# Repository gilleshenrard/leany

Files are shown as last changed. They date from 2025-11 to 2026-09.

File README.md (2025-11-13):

<!--
SPDX-FileCopyrightText: 2025 Gilles Henrard <contact@gilleshenrard.com>

SPDX-License-Identifier: MIT
-->

# Leany - An open-Source Inclinometer

Leany is a fully open-source, production-ready inclinometer based on an ARM Cortex-M3 32-bits microcontroller.
It provides high-precision tilt measurements while adhering to strict embedded software and hardware design standards.

## About the Project
An inclinometer is a tool that measures how much something is tilted, specifically in two directions: pitch and roll.

- Pitch measures the tilt forward or backward. Imagine tilting your head down to look at your feet—that’s pitch.
- Roll measures the tilt side to side. It’s like tilting your head left or right to look over your shoulder—that’s roll.

So, if you're using an inclinometer, it can tell you exactly how much something is tilted forward, backward, or side to side. For example, if you're setting up equipment, you can use the inclinometer to make sure it’s positioned correctly, with no unwanted tilt in either direction. It’s useful in many situations, from construction to vehicles, ensuring that everything is set at the right angle for safety and precision.

Leany is designed for engineers, makers, and professionals who need a reliable, open, and customizable inclinometer. It offers precise tilt measurements and multiple operating modes while maintaining a strong focus on code quality, hardware reliability, and ease of integration.

### Key Features

- **Measurements**: Supports pitch and roll rotation axes with a precision of up to **0.1°**.
- **Hold Function**: Freezes screen updates to keep a measurement visible.
- **Slope Mode**: Measures angles relative to gravity (**absolute measurements**).
- **Angle Mode**: Measures angles relative to a user-defined zero position (**relative measurements**).

## Getting Started

Before contributing, please run the following :
```
git config --local include.path ../.gitconfig
```

To learn more about each part of the project, check the respective directories:

- **[Firmware (`firmware/`)](firmware/)** – Contains the firmware source code and instructions on how to build and flash it.
- **[PCB Design (`pcb/`)](pcb/)** – Contains the schematics and board design, along with instructions on generating production files.
- **[Documentation templates (`templates/`)](templates/)** – Contains example files to illustrate the structure documentation files should have.

## Contributions & Community

Leany is managed with the help of a **[Github Project](https://github.com/users/gilleshenrard/projects/3)**

Leany is fully open-source, and contributions are welcome! If you find a bug, have a suggestion, or want to improve the project, feel free to open an issue or submit a pull request.

Discussions are also encouraged—whether it's feature ideas, improvements, or troubleshooting. Join the community and help make Leany even better!

## License

This project is licensed under the **MIT License**, allowing for flexible use and modification.

---

Feel free to suggest any changes or enhancements to this README! 🚀

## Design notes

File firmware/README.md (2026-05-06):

<!--
SPDX-FileCopyrightText: 2025 Gilles Henrard <contact@gilleshenrard.com>

SPDX-License-Identifier: MIT
-->





# Leany Firmware

Firmware for **Leany**, an inclinometer project based on the **STM32F103 (ARM Cortex-M3)** microcontroller.

## Building the Firmware

1. Install the required tools by running the appropriate prerequisites installation script in `resources/`.
2. Run the following commands, with either **Debug** or **Release** as a configuration name :
```
cmake --preset Release
cmake --build --preset Release
```
3. When the build task is complete, the firmware binary file (*.elf) can be found under build/<configuration_name>/

## Run unit-testing
1. Install the required tools by running the appropriate prerequisites installation script in `resources/`.
2. Run the following commands :
```
cmake --preset HOSTgcc
cmake --build --preset Tests
ctest --preset Tests
```

## Programming the device
### USB (programming only)
1. Plug the device to a computer with a USB type C cable
2. Press and maintain the ZERO button down
3. Press the RESET button
4. Release the ZERO button
5. Upload the Leany.elf file to the device with the STM32CubeProgrammer software in Serial mode

### Hardware programmer (programming and debugging)
1. Wire the programmer to the 4-pin male SWD connector on the PCB
2. Connect the programmer to a computer via USB
3. Flash and debug the firmware with an IDE of your choosing

## USB Command-Line Communication

The device supports bidirectional command-line communication over **USB Type-C**, appearing as a **virtual COM port**.  
When connected, look for a port name containing **`CH340`**, which indicates the onboard USB–serial bridge.

### Features

- **Command Protocol:**  
  A custom protocol inspired by **SCPI** is implemented to allow both **read** and **write** operations.  
  Note: The current implementation does *not yet* fully comply with the SCPI standard.

- **Logging System:**  
  The firmware outputs log messages prefixed with an exclamation mark (`!`).  
  Multiple **logging levels** are available to adjust verbosity as needed.

### Example Session

```text
:imu:ki?
0.5
:imu:ki 1.2
!Mahony kI updated
:imu:ki?
1.2
```

## CI/CD workflows
The firmware is instected by a [Github Action](https://github.com/gilleshenrard/leany/actions/workflows/firmware_build_lint.yml) upon push and pull request to ensure the software compiles and the linters are all ran.

## Project Structure

```
firmware/
├───cmake/
│   ├───templates/
│   ├───gcc-arm-none-eabi.cmake
│   ├───gcc.cmake
│   └───starm-clang.cmake
├───hardware/
├───resources/
│   ├───.vscode/
│   ├───check_filenames.sh
│   ├───install_prerequisites_ubuntu.sh
│   └───install_prerequisites_windows.bat
├───tasks/
├───ui/
├───tests/
├───utils/
├───CMakeLists.json
├───CMakePresets.json
└───Doxyfile
```

### `CMakeLists.json` and `CMakePresets.json`
This project is built with CMake to ensure maximum portability across different environments and OSes.

GCC and Clang toolchain files, as well as CMake preset configurations are provided to make building the firmware as easy as possible.

The toolchain files can be found under `cmake/`

### `cmake/templates`
Contains templates of files of which some fields need to be updated by CMake.

e.g. README.md shows the current firmware version, which is provided by CMake

### `Doxyfile`
Configuration for Doxygen documentation generation.

### `Leany.ioc`
The **STM32CubeMX** project file used to configure the STM32F103 microcontroller. It generates all third-party libraries, including LL (Low Level) and CMSIS.

### `resources/`
Contains additional resources:
- **`install_prerequisites_ubuntu.sh`**: Script to install everything needed to build the firmware on Ubuntu.
- **`install_prerequisites_windows.bat`**: Script to install everything needed to build the firmware on Windows.
- **`check_filenames.sh`**: Script to make sure the filenames formatting is respected.

### `resources/.vscode/`
Contains project-specific VSCode configuration and useful tasks. Should someone want to use it, they simply need to copy .vscode/ to the root of firmware/ :
- **`extensions.json`**: List of recommended VSCode extensions to use with this project. They will be suggested by VSCode if not already installed.
- **`launch.json`**: Configuration for OpenOCD to use an STLink to debug the application
- **`settings.json`**: Project-specific settings. They will override the user's pre-existing settings, and will ensure everyone uses the same configuration.
- **`tasks.json`**: Some useful custom tasks for VSCode on Windows and Ubuntu.

### `tasks/`
Contains the implementation of all the FreeRTOS tasks running in parallel.

### `hardware/`
Contains the implementation of the hardware modules (e.g. GPIO buttons, IMU sensor, ...)

### `ui/`
Contains the implementation of the user interface

### `utilities/`
Contains utility modules used across the whole applicaton (error stack, hardware events, ...)

### `tests/`
Contains a unit-testing suite

## Formatting, Code Quality, Linting, Documentation and licensing

- Google-style formatting is used and enforced with **clang-format** and **clang-tidy**
- Strict code quality is maintained with as many **GCC warnings** as possible enabled, all treated as errors.
- Linters configured: **clang-tidy**, **cppcheck**, **flawfinder**, and **lizard**.
- **Doxygen** is used for documentation, with strict control to ensure comprehensive code documentation.
- Licensing and copyrighting compliance is checked with **REUSE tool**
- Additional python scripts are used to perform checks such as enum and struct members documentation

## Contributing

Contributions to improve the firmware code and documentation are welcome. If you have any suggestions or improvements, please create a pull request or open an issue on the repository.

## License

Leany is licensed under the MIT license. See the LICENSE/ directory for more information.

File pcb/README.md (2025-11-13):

# Leany Project PCB Documentation

**Revision:** 0.3

Welcome to the Leany project's PCB documentation. This repository contains all the necessary files and information related to the PCB schematics and layouts for the Leany project.

pcb_overall PCB Overall

## Table of Contents

- [Introduction](#introduction)
- [Getting Started](#getting-started)
- [Directory Structure](#directory-structure)
- [Contributing](#contributing)
- [License](#license)

## Introduction

This documentation provides an overview of the PCB schematics and layouts used in the Leany project. It includes detailed information on the design, components, and assembly instructions.

## Generate the production files (Linux only)

1. Download KiCad from the [official website](https://kicad.org/).
2. Go to the pcb/ directory
3. Run the generation script located under resources/

## PCB fabrication

- Once the production files are generated, head to [JLCPCB](https://cart.jlcpcb.com/quote?orderType=1&stencilLayer=2&stencilWidth=100&stencilLength=100)

- Upload the zipped Gerber file, then, when the website is done processing it, choose the following non-default options :
  - Surface finish : LeadFree HASL
  - Enable PCB Assembly
- Then, click Next until arriving at the Bill Of Materials page.
- Upload the BOM and CPL files and click "Process BOM&CPL".
- Check that no error is shown on the components list page, and click Next.
- On the Components Placement page, move the components which are misplaced, then click Next.
- On the final page, click Save to Cart.

## Directory Structure
```
pcb/
├── 3d-models
└── resources
    └── generate_production_files.sh
```

### `3d-models`
This directory contains the additional 3D models needed to export the PCB as an STL file.
All the models are organised as [source]/[author]/[file]

### `resources`
Contains additional resources :
- `generate_production_files.sh` : A script to automatically generate and organise production files, with respect to JLCPCB standards.

## CI/CD workflows
The PCB files are instected by a [Github Action](https://github.com/gilleshenrard/leany/actions/workflows/pcb_production_files.yml) upon push and pull request to run the **Electrical Rules Check** and **Design Rules Check** ensure the production files are easily generated.

## Gallery
pcb_front PCB Front
pcb_back PCB Back

## Contributing

Contributions to improve the PCB design and documentation are welcome. If you have any suggestions or improvements, please create a pull request or open an issue on the repository.

## License

The PCB files are licensed under CERN Open Hardware Licence Version 2 - Permissive. See the [CERN-OHL-P-2.0](https://github.com/gilleshenrard/leany/blob/27-fix-pcb-rev02-issues/LICENSES/CERN-OHL-P-2.0.txt) file for more details.

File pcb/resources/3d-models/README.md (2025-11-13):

# 3D Models Directory

This directory contains 3D models sourced from [GrabCAD](https://grabcad.com/library) and the [Wago website](https://www.wago.com/). The models are used to generate a 3D model of the PCB.

They are organized into subdirectories based on their source and authors.

## Directory Structure

- `grabcad/`
    - Contains subdirectories for each author with their respective 3D models.
- `wago/`
    - Contains 3D models sourced from the Wago website.

## GrabCAD Models

The `grabcad/` directory is organized by author. Each subdirectory within `grabcad/` is named after the author and contains the 3D models they have contributed.

Example structure:
```
grabcad/
├── author1/
│   ├── model1.stl
│   ├── model2.stl
│   └── ...
├── author2/
│   ├── model1.stl
│   ├── model2.stl
│   └── ...
└── ...
```

## Wago Models

The `wago/` directory contains 3D models sourced from the Wago website. These models are not organized by author.

Example structure:
```
wago/
├── model1.stl
├── model2.stl
└── ...
```

## Usage

You can use these 3D models for your projects by navigating to the respective directories and selecting the models you need.

## License

Please refer to the individual licenses provided by GrabCAD.com and the Wago website for the usage rights of these models.

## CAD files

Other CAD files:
cad/test_jig/pcb_coordinates.FCStd
pcb/resources/3d-models/wago/wago_2059-302_998-403.stp
cad/test_jig/support_plate.FCStd
cad/test_jig/angled_bracket.FCStd
pcb/resources/3d-models/grabcad/Ignaz_Kevenaar/2020-RGB-LED.step
pcb/resources/3d-models/grabcad/Mart_Berghs/Spacer-M2-M-F-10mm_mart-berghs.stp
pcb/resources/3d-models/grabcad/Mohamed_Owais/pin_header_male_2.54mm_0.1in_mohamed-owais.step
pcb/resources/3d-models/grabcad/Nhatkhongbuon/SOP-8.step
pcb/resources/3d-models/grabcad/Ni_Ni/USB_type_C_smd_12p_ni-ni.stp
pcb/resources/3d-models/grabcad/Pablo_Queiroz/1.8_inches_128x160_RGB_TFT_LCD_Pablo-Queiroz.stp
pcb/resources/3d-models/grabcad/Paul_Thelu/tact_switch_2.5mm_paul-thelu.stp
pcb/resources/3d-models/grabcad/Stelian_Stefan/SW-DTSM-66N-V_Nicola-Stelian-Stefan.stp

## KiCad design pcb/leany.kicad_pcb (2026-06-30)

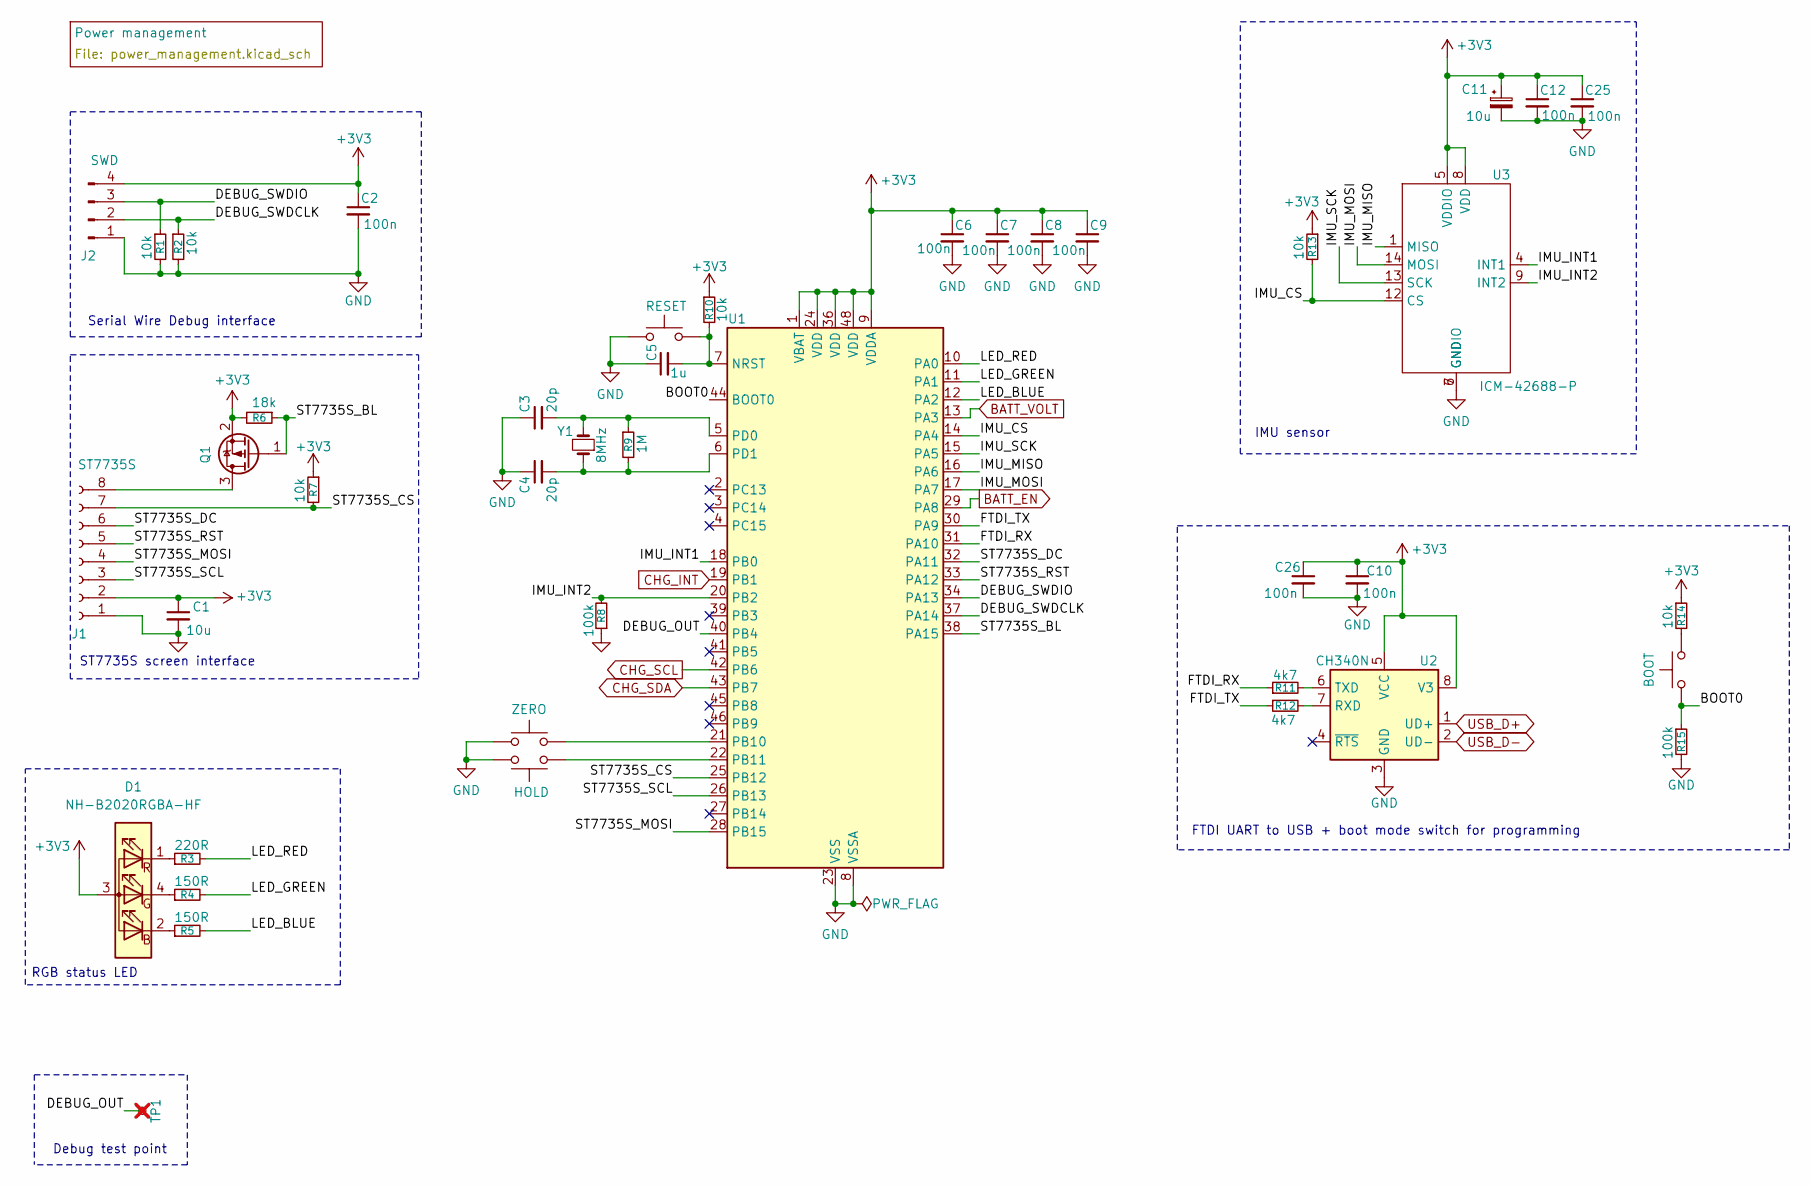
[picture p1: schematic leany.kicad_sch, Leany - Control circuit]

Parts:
C1, C11: 10u; C_0805_2012Metric; LCSC C15850
C2, C6, C7, C8, C9, C10, C12, C25, C26: 100n; C_0402_1005Metric; LCSC C1525
C3, C4: 20p; C_0402_1005Metric; LCSC C1554
C5: 1u; C_0402_1005Metric; LCSC C52923
D1: NH-B2020RGBA-HF; LCSC C2874116
J1: ST7735S; LCSC C5224027
J2: SWD; PinHeader_1x04_P2.54mm_Horizontal; LCSC C2935929
Q1: AO3401A; SOT-23; LCSC C15127
R1, R2, R7, R10, R13, R14: 10k; R_0402_1005Metric; LCSC C25744
R3: 220R; R_0402_1005Metric; LCSC C25091
R4, R5: 150R; R_0603_1608Metric; LCSC C22808
R6: 18k; R_0603_1608Metric; LCSC C25810
R8, R15: 100k; R_0402_1005Metric; LCSC C25741
R9: 1M; R_0402_1005Metric; LCSC C26083
R11, R12: 4k7; R_0402_1005Metric; LCSC C25900
SW1: ZERO; SW_Push_1P1T_NO_6x6mm_H9.5mm; LCSC C455120
SW2: HOLD; SW_Push_1P1T_NO_6x6mm_H9.5mm; LCSC C455120
SW3: RESET; SW_Push_1P1T_XKB_TS-1187A; LCSC C318884
SW4: BOOT; SW_Push_1P1T_XKB_TS-1187A; LCSC C318884
TP1: DEBUG_OUT; TestPoint_Pad_1.0x1.0mm; not fitted
U1: STM32F103C8Tx; LQFP-48_7x7mm_P0.5mm; LCSC C8734
U2: CH340N; SOP-8_3.9x4.9mm_P1.27mm; LCSC C2977777
U3: ICM-42688-P; LGA-14_3x2.5mm_P0.5mm_LayoutBorder3x4y; LCSC C784817
Y1: 8MHz; Crystal_SMD_Abracon_ABM3-2Pin_5.0x3.2mm; LCSC C115962

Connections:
+3V3: C1.1, C2.1, C6.1, C7.1, C8.1, C9.1, C10.1, C11.1, C12.1, C25.1, C26.1, D1.3 (A), J1.2, J2.4, Q1.2 (S), R6.2, R7.1, R10.1, R13.1, R14.1, U1.1 (VBAT), U1.9 (VDDA), U1.24 (VDD), U1.36 (VDD), U1.48 (VDD), U2.5 (VCC), U2.8 (V3), U3.5 (VDDIO), U3.8 (VDD); also elsewhere on the board
/BOOT0: R15.1, SW4.2, U1.44 (BOOT0)
/DEBUG_OUT: TP1.1 (1_1), U1.40 (PB4)
/DEBUG_SWDCLK: J2.2, R2.1, U1.37 (PA14)
/DEBUG_SWDIO: J2.3, R1.1, U1.34 (PA13)
/FTDI_RX: R11.1, U1.31 (PA10)
/FTDI_TX: R12.1, U1.30 (PA9)
/IMU_CS: R13.2, U1.14 (PA4), U3.12 (CS)
/IMU_INT1: U1.18 (PB0), U3.4 (INT1)
/IMU_INT2: R8.2, U1.20 (PB2), U3.9 (INT2)
/IMU_MISO: U1.16 (PA6), U3.1 (MISO)
/IMU_MOSI: U1.17 (PA7), U3.14 (MOSI)
/IMU_SCK: U1.15 (PA5), U3.13 (SCK)
/LED_BLUE: R5.2, U1.12 (PA2)
/LED_GREEN: R4.2, U1.11 (PA1)
/LED_RED: R3.2, U1.10 (PA0)
/ST7735S_BL: Q1.1 (G), R6.1, U1.38 (PA15)
/ST7735S_CS: J1.7, R7.2, U1.25 (PB12)
/ST7735S_DC: J1.6, U1.32 (PA11)
/ST7735S_MOSI: J1.4, U1.28 (PB15)
/ST7735S_RST: J1.5, U1.33 (PA12)
/ST7735S_SCL: J1.3, U1.26 (PB13)
BATT_EN: U1.29 (PA8); also elsewhere on the board
BATT_VOLT: U1.13 (PA3); also elsewhere on the board
CHG_INT: U1.19 (PB1); also elsewhere on the board
CHG_SCL: U1.42 (PB6); also elsewhere on the board
CHG_SDA: U1.43 (PB7); also elsewhere on the board
GND: C1.2, C2.2, C3.1, C4.1, C5.1, C6.2, C7.2, C8.2, C9.2, C10.2, C11.2, C12.2, C25.2, C26.2, J1.1, J2.1, R1.2, R2.2, R8.1, R15.2, SW1.2, SW2.1, SW3.1, U1.8 (VSSA), U1.23 (VSS), U1.35 (VSS), U1.47 (VSS), U2.3 (GND), U3.6 (GNDIO), U3.7 (GND); also elsewhere on the board
unnamed: D1.2 (BK), R5.1
unnamed: D1.4 (GK), R4.1
unnamed: D1.1 (RK), R3.1
unnamed: J1.8, Q1.3 (D)
unnamed: R14.2, SW4.1
unnamed: C5.2, R10.2, SW3.2, U1.7 (NRST)
unnamed: SW1.1, U1.21 (PB10)
unnamed: SW2.2, U1.22 (PB11)
unnamed: C3.2, R9.1, U1.5 (PD0), Y1.2
unnamed: C4.2, R9.2, U1.6 (PD1), Y1.1
unnamed: R12.2, U2.7 (RXD)
unnamed: R11.2, U2.6 (TXD)
USB_D+: U2.1 (UD+); also elsewhere on the board
USB_D-: U2.2 (UD-); also elsewhere on the board

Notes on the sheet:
FTDI UART to USB + boot mode switch for programming
IMU sensor
Debug test point
ST7735S screen interface
RGB status LED
Serial Wire Debug interface

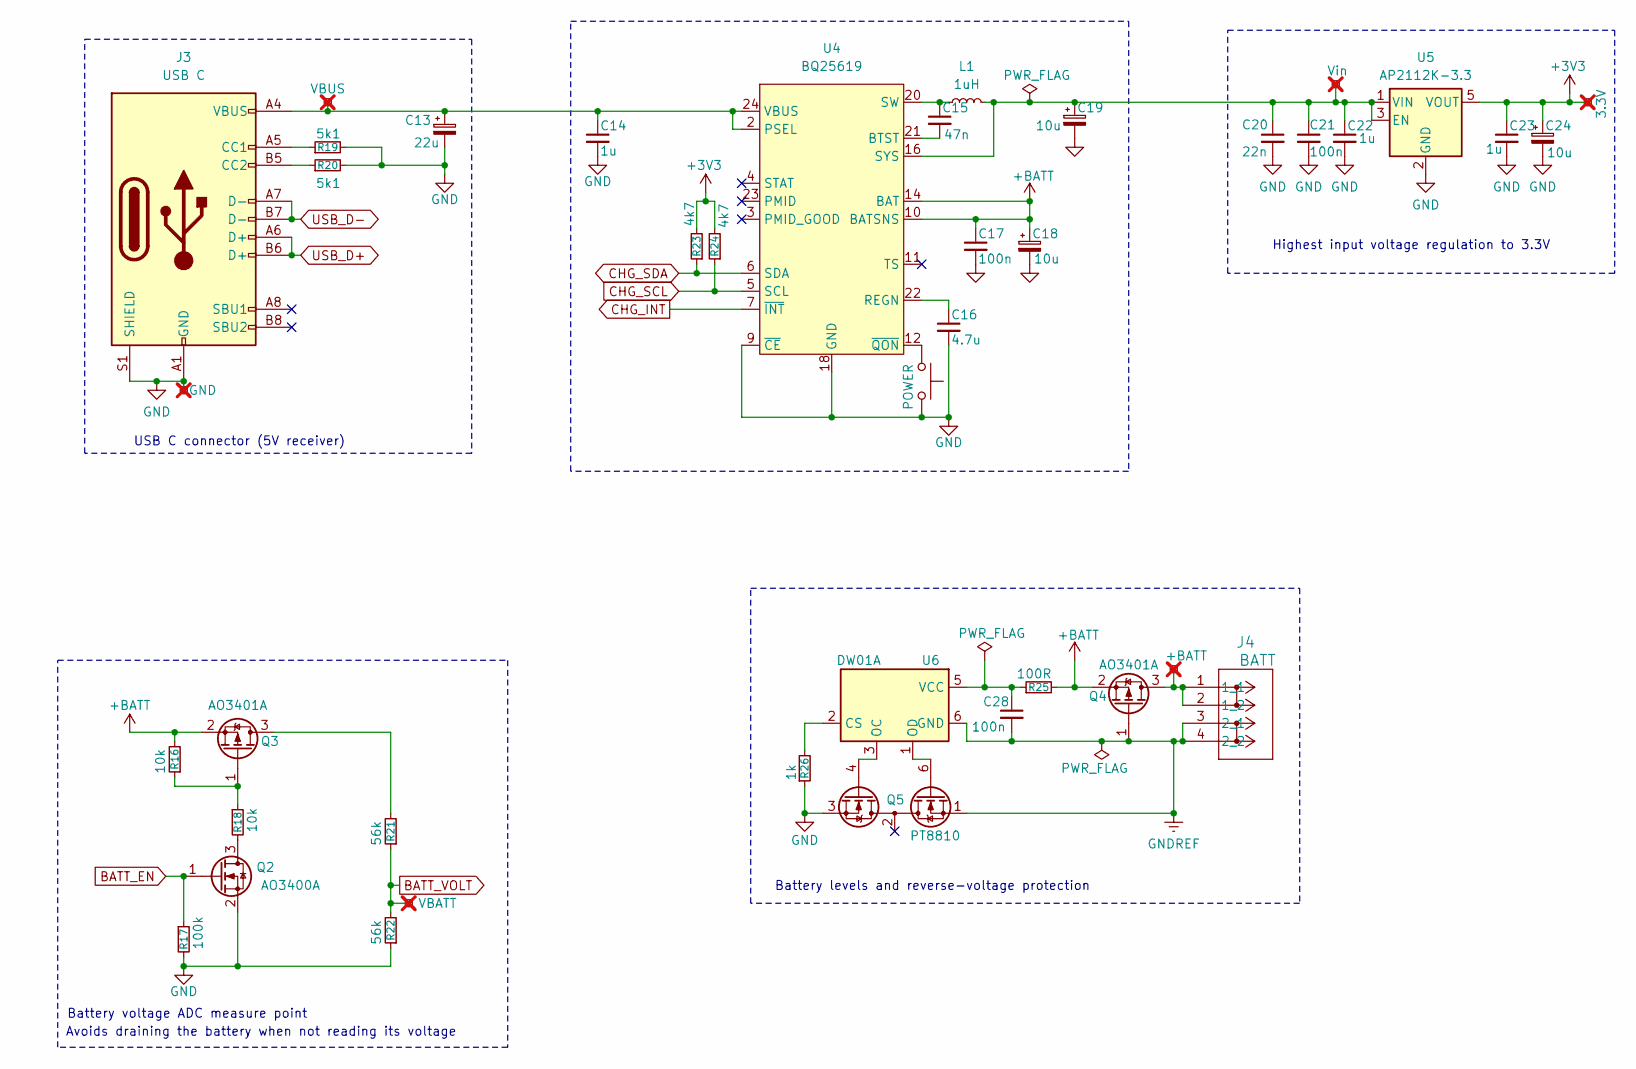
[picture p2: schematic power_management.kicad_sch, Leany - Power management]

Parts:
C13: 22u; C_0805_2012Metric; LCSC C45783
C14, C22, C23: 1u; C_0402_1005Metric; LCSC C52923
C15: 47n; C_0603_1608Metric; LCSC C1622
C16: 4.7u; C_0805_2012Metric; LCSC C1779
C17, C21, C28: 100n; C_0402_1005Metric; LCSC C1525
C18, C19, C24: 10u; C_0805_2012Metric; LCSC C15850
C20: 22n; C_0402_1005Metric; LCSC C1532
J3: USB C; USB_C_Receptacle_HRO_TYPE-C-31-M-12; LCSC C136423
J4: BATT; wago_2059-302_998-403; LCSC C2765060
L1: 1uH; L_1008_2520Metric; LCSC C98345
Q2: AO3400A; SOT-23; LCSC C20917
Q3, Q4: AO3401A; SOT-23; LCSC C15127
Q5: PT8810; SOT-23-6; LCSC C351413
R16, R18: 10k; R_0402_1005Metric; LCSC C25744
R17: 100k; R_0402_1005Metric; LCSC C25741
R19, R20: 5k1; R_0402_1005Metric; LCSC C25905
R21, R22: 56k; R_0603_1608Metric; LCSC C23206
R23, R24: 4k7; R_0402_1005Metric; LCSC C25900
R25: 100R; R_0402_1005Metric; LCSC C25076
R26: 1k; R_0402_1005Metric; LCSC C11702
SW5: POWER; SW_Tactile_SPST_Angled_PTS645Vx31-2LFS; LCSC C730034
TP2: GND; TestPoint_Pad_1.0x1.0mm; not fitted
TP3: VBUS; TestPoint_Pad_1.0x1.0mm; not fitted
TP4: VBATT; TestPoint_Pad_1.0x1.0mm; not fitted
TP5: +BATT; TestPoint_Pad_1.0x1.0mm; not fitted
TP6: Vin; TestPoint_Pad_1.0x1.0mm; not fitted
TP7: 3.3V; TestPoint_Pad_1.0x1.0mm; not fitted
U4: BQ25619; Texas_RGE0024H_VQFN-24-1EP_4x4mm_P0.5mm_EP2.7x2.7mm_Thermal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; LCSC C2864534
U5: AP2112K-3.3; SOT-23-5; LCSC C3021085
U6: DW01A; SOT-23-6; LCSC C2927799

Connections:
+3V3: C23.1, C24.1, R23.2, R24.2, TP7.1 (1_1), U5.5 (VOUT); also elsewhere on the board
+BATT: C17.1, C18.1, Q3.2 (S), Q4.2 (S), R16.2, R25.2, U4.10 (BATSNS), U4.13 (BAT), U4.14 (BAT)
BATT_EN: Q2.1 (G), R17.1; also elsewhere on the board
BATT_VOLT: R21.1, R22.2, TP4.1 (1_1); also elsewhere on the board
CHG_INT: U4.7 (~INT); also elsewhere on the board
CHG_SCL: R24.1, U4.5 (SCL); also elsewhere on the board
CHG_SDA: R23.1, U4.6 (SDA); also elsewhere on the board
GND: C13.2, C14.2, C16.2, C17.2, C18.2, C19.2, C20.2, C21.2, C22.2, C23.2, C24.2, J3.A1 (GND), J3.A12 (GND), J3.B1 (GND), J3.B12 (GND), J3.S1 (SHIELD), Q2.2 (S), Q5.3 (S2), R17.2, R19.2, R20.2, R22.1, R26.1, SW5.2, TP2.1 (1_1), U4.9 (~CE), U4.17 (GND), U4.18 (GND), U4.25 (GND), U5.2 (GND); also elsewhere on the board
GNDREF: C28.2, J4.3 (2_1), J4.4 (2_2), Q4.1 (G), Q5.1 (D1), U6.6 (GND)
unnamed: C15.1, L1.1, U4.19 (SW), U4.20 (SW)
unnamed: J3.A5 (CC1), R19.1
unnamed: J3.B5 (CC2), R20.1
unnamed: J4.1 (1_1), J4.2 (1_2), Q4.3 (D), TP5.1 (1_1)
unnamed: Q2.3 (D), R18.2
unnamed: Q3.3 (D), R21.2
unnamed: Q3.1 (G), R16.1, R18.1
unnamed: Q5.6 (G1), U6.1 (OD)
unnamed: Q5.4 (G2), U6.3 (OC)
unnamed: C15.2, U4.21 (BTST)
unnamed: C13.1, C14.1, J3.A4 (VBUS), J3.A9 (VBUS), J3.B4 (VBUS), J3.B9 (VBUS), TP3.1 (1_1), U4.1 (VAC), U4.2 (PSEL), U4.24 (VBUS)
unnamed: C16.1, U4.22 (REGN)
unnamed: SW5.1, U4.12 (~QON)
unnamed: R26.2, U6.2 (CS)
unnamed: C28.1, R25.1, U6.5 (VCC)
SYS: C19.1, C20.1, C21.1, C22.1, L1.2, TP6.1 (1_1), U4.15 (SYS), U4.16 (SYS), U5.1 (VIN), U5.3 (EN)
USB_D+: J3.A6 (D+), J3.B6 (D+); also elsewhere on the board
USB_D-: J3.A7 (D-), J3.B7 (D-); also elsewhere on the board

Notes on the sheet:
USB C connector (5V receiver)
Battery levels and reverse-voltage protection
Battery voltage ADC measure point
Highest input voltage regulation to 3.3V
Avoids draining the battery when not reading its voltage

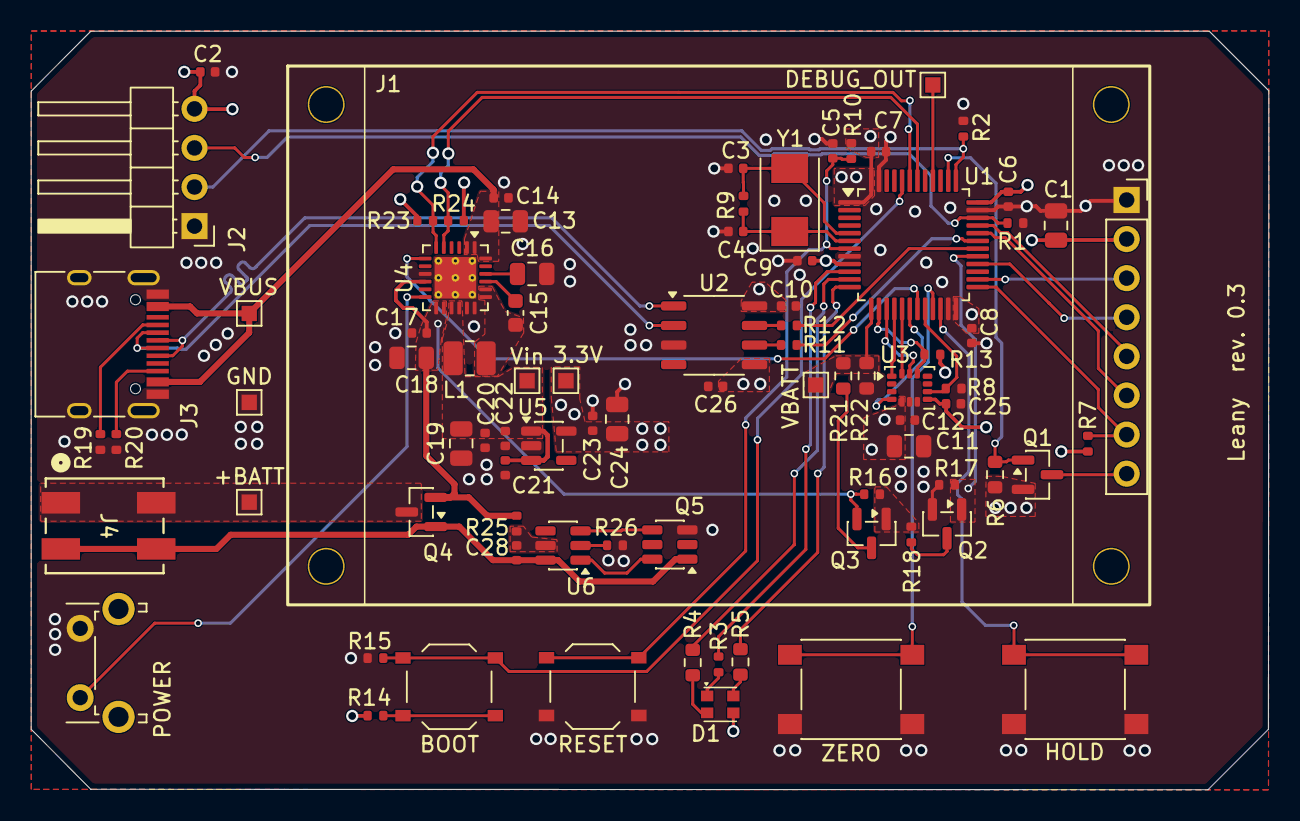
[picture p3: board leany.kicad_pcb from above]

Board: 4 copper layers, 80.4 x 49.3 mm, 83 parts (0 on the bottom side), 60 nets.

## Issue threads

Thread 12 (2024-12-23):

Implement battery management

gilleshenrard, 2024-12-23:
- [ ] Freertos task
- [ ] Task delays
- [ ] ADC readings
- [ ] Thresholds calculation
- [ ] Charger status inputs
- [ ] Battery messages to display

gilleshenrard, 2025-09-22:
Tests done on the hardware :
- Reverse-polarity protection FET works properly, with negligeable forward-voltage drop
- DW01A cuts off at 2.4V, and gets back up at 3V, as expected
- DW01A does not cut off at 4.3V as it should, but a 0.6V drop has been observed... A misplaced diode is suspected

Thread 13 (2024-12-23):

Implement status LED

gilleshenrard, 2024-12-23:
- [ ] pwm and open-drain pins? for effects and custom colours
- [ ] Migrate buttons FreeRTOS task to a GPIO task, running buttons and LED state machines
- [ ] Add debug pin library to GPIO module (GPIO changes into critical sections)
- [ ] State-based patterns
- [ ] State change mutex

Closed 2025-08-29.

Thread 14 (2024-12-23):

Hardware startup diagnostics

gilleshenrard, 2024-12-23:
- [ ] LSM6DSO diagnostic
- [ ] ST7735S diagnostic
- [ ] Buttons diagnostic
- [ ] Charger diagnostic
- [ ] Battery level diagnostic
- [ ] Status LED diagnostic

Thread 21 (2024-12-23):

Fix PCBv1 issues

gilleshenrard, 2024-12-23:
- [x] Add a reset button with debounce capacitor and 10k pull-up to NRST (pin 7).
- [x] Add a 100k pull-down resistor to BOOT1
- [x] Add 10k pull-down resistors to SWD
- [x] add 4.7k series resistors between STM32 and CH340C
- [x] Fix the Crystal used
  - Wrong footprint on BOM
- [x] source a different status LED
  - The one chosen seems to be out of the LCSC's catalog
- [x] change the LED current-limiting resistor values
- [x] Replace the boot mode SPDT switch by a simple push button
  - Makes sure the user will release it after programming
  - More compact
  - Easier to source

Like so :
+3.3V ---- 10kΩ ---- button ---- BOOT0 ---- 100kΩ ---- GND

- [x] Move all components on one face
  - Avoids having to pay for standard assembly, which is very expensive
- [x] Ditch  the 18650 holder for a Wago THT connector and the user will source a holder with wires attached
- [x] Add decoupling capacitors to the line between the Wago connector and BATSNS
- [ ] Fix orientations on BOM
  - so it does not have to be changed manually
- [x] Get rid of the JLCPCB KiCAD plugin
  - The LSM6DSO forces standard assembly with JLCPCB, which is expensive
  - Helpful to build the BOM and drill files, but defeats the goal of making the setup as simple as possible for users
- [ ] re-specify what should be ignored from mounting or ignored from BOM
- [ ] Match the data transmission lines' lengths
- [x] Add silkscreen to indicate SWD and ST7735S pins
- [ ] Add missing 3D models
- [x] Add board version silkscreen
- [x] Add Wago wire gauge and length information silkscreen at the back
- [ ] Add battery reverse-polarity protection
- [x] Source another MEMS sensor

gilleshenrard, 2024-12-29:
Debug issues diagnostics workflow :
- Debugging works on a bluepill
- CH340 is recognised as a COM device
- when disabling monitor resetting in cortex-debug settings in launch.json, works but only catching currently running program
- possible to connect to the MCU with STM32CubeProgrammer when booting after flipping bootmode switch
- PB2 (BOOT1) is directly connected to LSM6DSO INT2, and should have a 100K pull-down resistor to prevent selecting embedded SRAM instead of System memory (bootloader) as boot space

gilleshenrard, 2024-12-31:
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

After soldering a 100k resistor to PB2 and GND, no immediate changes

gilleshenrard, 2024-12-31:
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

After soldering a 100k resistor to PB2 and GND, no immediate changes

gilleshenrard, 2024-12-31:
NRST (pin 7) is internally connected to a pull-up resistor and does not need to be connected to VDD. updating todo list

Closed 2025-02-16.

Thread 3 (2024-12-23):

Design PCBv1

gilleshenrard, 2024-12-23:
- [x] Schematic
- [x] JCLPCB design rules
- [x] PCB Design

gilleshenrard, 2024-12-23:
First order made.
To do in a future issue :

Closed 2024-12-23.

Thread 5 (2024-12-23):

Implement the LSM6DSO

gilleshenrard, 2024-12-23:
- [ ] Freertos task
- [ ] SPI basic communication
- [ ] Gathering measurements
- [ ] Complementary filter
- [ ] Optimise state machine for static analysis
- [ ] Value change threshold
- [ ] Oscilloscope timing tests
- [ ] Signal stabilisation
- [ ] Temperature compensation
- [ ] Calibration

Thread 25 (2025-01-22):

Modify project directories structure

gilleshenrard, 2025-01-22:
/leany
  ├── firmware/
  │    ├── src/                # Source code
  │    ├── include/            # Headers
  │    ├── CMakeLists.txt      # Build system
  │    └── README.md           # Firmware-specific info
  │
  ├── hardware/
  │    ├── schematics/         # EDA files (e.g., KiCAD, Eagle)
  │    ├── gerbers/            # Manufacturing files
  │    ├── bom/                # Bill of Materials
  │    └── README.md           # Hardware-specific info
   |
  ├── enclosure/
  │    ├── 3d_models/          # STL, STEP, and other 3D files
  │    ├── source_files/       # Original CAD files (e.g., Fusion 360, SolidWorks)
  │    ├── README.md           # Instructions for printing and assembly
  │    └── changelog.md        # Versioning details for the enclosure
  │
  ├── docs/
  │    ├── changelogs/         # Separate changelogs for firmware and hardware
  │    ├── user_manuals/       # Documentation for end-users
  │    └── developer_docs/     # Technical details for developers
  │
  ├── LICENSE
  ├── README.md                # Overview of the entire repository
  └── .github/                 # GitHub-specific workflows and project files
       ├── workflows/          # CI/CD workflows for builds and releases
       ├── ISSUE_TEMPLATE/     # Issue templates for firmware and hardware
       └── PULL_REQUEST_TEMPLATE.md

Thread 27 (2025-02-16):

fix PCB rev0.2 issues

gilleshenrard, 2025-02-16:
- [x] re-specify what should be ignored from mounting or ignored from BOM
- [x] Match the USB differential data transmission lines' lengths
- [x] Add missing 3D models
- [x] Reassign 3D models to footprints in the library
- [x] Migrate 3D files and PCB to LFS
- [x] Add battery reverse-polarity protection
- [x] Fix buttons silkscreen
- [x] Remove SPI pull-up resistors exceps CS
- [x] Add test pad to override battery connector + so a power data logger such as an INA219 can be put in series with 3.3V
- [x] Add a soldering pad to easily connect an oscilloscope to the debug pin (+pulldown?)
- [x] replace the CH340C by a CH340N (more compact)
- [x] add DW01A battery protector
- [x] check status LED footprint
- [x] add license information in project and files
- [x] Replace basic components with smaller footprints and update BOM accordingly
- [x] Fix silkscreen warnings
- [x] Reroute tracks (thinner? 4 layers?)
- [x] Add pictures of the PCB in the README (LFS)

IMPORTANT :
- [x] Replace the BMI270 by a drop-in replacement (see [#63](https://github.com/gilleshenrard/leany/issues/63))
- [x] Make the IMU symbol and footprint generic so as to accomodate model changes (in firmware project too)
- [x] ZERO, HOLD, RESET, FLASH buttons raise the following error in JLCPCB : "Multiple lines in the BOM have been matched to the same part. Please check if the matching is correct."
- [x] WAGO connectors are out of stock

Closed 2025-09-15.

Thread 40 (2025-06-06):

Improve Mahony filtering

gilleshenrard, 2025-06-06:
- [x] Use registers SENSOR_TIME_[0-2] for the actual time base instead of the theoretical sampling rate
- [x] Add zero-division protections, however improbable, for good practice
- [x] Add linear motion filtering (dot product + norm value checking)
- [x] Make library thread-safe by replacing global quaternion and integrals by function parameters
- [x] Improve firmware linting workflow by using a single task in a single VM and a continue-on-error behaviour

Closed 2025-07-14.

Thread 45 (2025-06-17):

Implement test jigs

gilleshenrard, 2025-06-17:
The idea is to have some support on which solidly attach the PCB, then slide said support on various jigs to test for known angles.
The fixtures should look like bent plates the user can rock back an forth, so the PCB would lean flat on the bench, then be rotated around one axis for a certain angle until the second part of the plate lays flat on the bench.
Multiple jigs should allow for 15°, 30°, 45°, 60° and 90° tests
The PCB support should be attachable either way so both pitch and roll can be tested

- [ ] design a 3D printable plate to which attach the PCB
- [ ] design various fixtures onto which slide the PCB plate

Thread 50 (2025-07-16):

Strengthen Mahony Filter

gilleshenrard, 2025-07-16:
- [x] Make sure to check for upper bound (1.0F + 1e-5F) when verifying estimations and accelerometer alignment
       This is to make sure the dot product does not yield some funky result
- [x] Move quaternion, error integrals, PI gains and update timestamps into a filter context structure for usability
- [x] Change Mahony parameter dtPeriod_sec to the current IMU timestamp and let Mahony update timestamps only on valid updates
- [x] Include timestamps in reset mechanism
- [x] Reuse CLOSE_TO_ZERO variable instead of NO_INTEGRAL_GAIN
- [x] Copy accelerometer array in a local variable instead of modifying it in-place
- [x] Reset the current attitude quaternion to default values if its norm is close to zero after normalisation?
- [x] Clamp integratedErrors[] between a min and a max values to avoid windup
- [x] Make validation bounds global static instead of hard-coded in the functions
- [x] Add time delta verifications to make sure dt doesn't get too high if updates skips (integral error overshoot)
- [ ] Fix clang-tidy and Doxygen errors

Closed 2025-07-17.

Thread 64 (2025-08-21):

fix PCB rev0.3 issues

gilleshenrard, 2025-08-21:
- [ ] Move drill origin to fix pick and place positioning
       PCB Bottom-left corner so the coordinates are always positive?
       PCB center so the STEP file is origin-centered?
- [x] re-specify what should be ignored from mounting or ignored from BOM
- [x] Match the USB differential data transmission lines' lengths
- [x] Add missing 3D models
- [x] Reassign 3D models to footprints in the library
- [ ] Migrate 3D files and PCB to LFS
- [x] Add battery reverse-polarity protection
- [x] Fix buttons silkscreen
- [x] Remove SPI pull-up resistors exceps CS
- [x] Add test pad to override battery connector + so a power data logger such as an INA219 can be put in series with 3.3V
- [x] Add a soldering pad to easily connect an oscilloscope to the debug pin (+pulldown?)
- [x] replace the CH340C by a CH340N (more compact)
- [x] add DW01A battery protector
- [x] check status LED footprint
- [x] add license information in project and files
- [x] Replace basic components with smaller footprints and update BOM accordingly
- [x] Fix silkscreen warnings
- [ ] Reroute tracks (thinner? 4 layers?)
- [ ] Add a check for parity between PCB and schematic in DRC
- [ ] Make it so updating the PCB does not erase ERC exclusions

IMPORTANT :
- [x] Replace the BMI270 by a drop-in replacement (see [#63](https://github.com/gilleshenrard/leany/issues/63))
- [x] Make the IMU symbol and footprint generic so as to accomodate model changes (in firmware project too)
- [x] ZERO, HOLD, RESET, FLASH buttons raise the following error in JLCPCB : "Multiple lines in the BOM have been matched to the same part. Please check if the matching is correct."
- [x] WAGO connectors are out of stock

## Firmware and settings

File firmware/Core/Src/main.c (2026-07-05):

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
/* Includes ------------------------------------------------------------------*/
#include "main.h"
#include "cmsis_os.h"
#include "adc.h"
#include "dma.h"
#include "i2c.h"
#include "iwdg.h"
#include "spi.h"
#include "tim.h"
#include "usart.h"
#include "gpio.h"

/* USER CODE BEGIN Includes */
#include "hardware_events.h"
#include "systick.h"
#include "task_dispatcher.h"
#include "task_gpio.h"
#include "task_imu.h"
#include "task_ui.h"
#include "task_serial.h"
#include "task_battery.h"

/* USER CODE END Includes */


void SystemClock_Config(void);
void MX_FREERTOS_Init(void);
/* USER CODE BEGIN PFP */
extern inline bool isError(const ErrorCode code);
/* USER CODE END PFP */

/**
  * @brief  The application entry point.
  * @retval int
  */
int main(void)
{

  /* USER CODE BEGIN 1 */
    uint8_t holdingValues = 0;
  /* USER CODE END 1 */

  /* MCU Configuration--------------------------------------------------------*/

  /* Reset of all peripherals, Initializes the Flash interface and the Systick. */
  HAL_Init();

  /* Configure the system clock */
  SystemClock_Config();

  /* USER CODE BEGIN SysInit */
  primeHSEOscillator();
  /* USER CODE END SysInit */

  /* Initialize all configured peripherals */
  MX_GPIO_Init();
  MX_DMA_Init();
  MX_ADC1_Init();
  MX_IWDG_Init();
  MX_SPI1_Init();
  MX_SPI2_Init();
  MX_USART1_UART_Init();
  MX_I2C1_Init();
  MX_TIM2_Init();
  /* USER CODE BEGIN 2 */
    createHardwareEventsGroup();
    createIMUtask();
    createGPIOtask();
    (void)createUItask();
    createSerialtask();
    (void)createBatteryTask();
    (void)createMessageDispatchertask();
  /* USER CODE END 2 */

  /* Call init function for freertos objects (in cmsis_os2.c) */
  MX_FREERTOS_Init();

  /* Start scheduler */
  osKernelStart();

  /* We should never get here as control is now taken by the scheduler */

  /* Infinite loop */
  /* USER CODE BEGIN WHILE */
    while (1) {
        //reset the watchdog
        LL_IWDG_ReloadCounter(IWDG);
    /* USER CODE END WHILE */

    /* USER CODE BEGIN 3 */
    }
  /* USER CODE END 3 */
}

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
/**
  * @brief  Period elapsed callback in non blocking mode
  * @note   This function is called  when TIM1 interrupt took place, inside
  * HAL_TIM_IRQHandler(). It makes a direct call to HAL_IncTick() to increment
  * a global variable "uwTick" used as application time base.
  * @param  htim : TIM handle
  * @retval None
  */
void HAL_TIM_PeriodElapsedCallback(TIM_HandleTypeDef *htim)
{
  if (htim->Instance == TIM1)
  {
    HAL_IncTick();
  }
}

/**
  * @brief  This function is executed in case of error occurrence.
  * @retval None
  */
void Error_Handler(void)
{
  /* USER CODE BEGIN Error_Handler_Debug */
    /* User can add his own implementation to report the HAL error return state */
    __disable_irq();
    while (1) {
    }
  /* USER CODE END Error_Handler_Debug */
}
#ifdef USE_FULL_ASSERT
/**
  * @brief  Reports the name of the source file and the source line number
  *         where the assert_param error has occurred.
  * @param  file: pointer to the source file name
  * @param  line: assert_param error line source number
  * @retval None
  */
void assert_failed(uint8_t *file, uint32_t line)
{
  /* USER CODE BEGIN 6 */
    /* User can add his own implementation to report the file name and line number,
     ex: printf("Wrong parameters value: file %s on line %d\r\n", file, line) */
  /* USER CODE END 6 */
}
#endif /* USE_FULL_ASSERT */

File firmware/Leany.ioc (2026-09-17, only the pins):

Mcu.UserName=STM32F103C8Tx
PA0-WKUP.GPIO_Label=LED_RED
PA0-WKUP.Signal=S_TIM2_CH1_ETR
PA1.GPIO_Label=LED_GREEN
PA1.Signal=S_TIM2_CH2
PA10.GPIO_Label=FTDI_RX
PA10.Signal=USART1_RX
PA11.GPIO_Label=ST7735S_DC
PA11.Signal=GPIO_Output
PA12.GPIO_Label=ST7735S_RST
PA12.Signal=GPIO_Output
PA13.GPIO_Label=DEBUG_SWDIO
PA13.Signal=SYS_JTMS-SWDIO
PA14.GPIO_Label=DEBUG_SWCLK
PA14.Signal=SYS_JTCK-SWCLK
PA15.GPIO_Label=ST7735S_BL
PA15.Signal=GPIO_Output
PA2.GPIO_Label=LED_BLUE
PA2.Signal=S_TIM2_CH3
PA3.GPIO_Label=BATT_VOLT
PA3.Signal=ADCx_IN3
PA4.GPIO_Label=IMU_CS
PA4.Signal=GPIO_Output
PA5.GPIO_Label=IMU_SCL
PA5.Signal=SPI1_SCK
PA6.GPIO_Label=IMU_MISO
PA6.Signal=SPI1_MISO
PA7.GPIO_Label=IMU_MOSI
PA7.Signal=SPI1_MOSI
PA8.GPIO_Label=BATT_EN
PA8.Signal=GPIO_Output
PA9.GPIO_Label=FTDI_TX
PA9.Signal=USART1_TX
PB0.GPIO_Label=IMU_INT1
PB0.Signal=GPXTI0
PB1.GPIO_Label=CHG_INT
PB1.Signal=GPIO_Input
PB10.GPIO_Label=ZERO_BUTTON
PB10.Signal=GPIO_Input
PB11.GPIO_Label=HOLD_BUTTON
PB11.Signal=GPIO_Input
PB12.GPIO_Label=ST7735S_CS
PB12.Signal=GPIO_Output
PB13.GPIO_Label=ST7735S_SCL
PB13.Signal=SPI2_SCK
PB15.GPIO_Label=ST7735S_MOSI
PB15.Signal=SPI2_MOSI
PB2.GPIO_Label=IMU_INT2
PB2.Signal=GPXTI2
PB4.GPIO_Label=DEBUG_OUT
PB4.Signal=GPIO_Output
PB6.GPIO_Label=CHG_SCL
PB6.Signal=I2C1_SCL
PB7.GPIO_Label=CHG_SDA
PB7.Signal=I2C1_SDA
PD0-OSC_IN.Signal=RCC_OSC_IN
PD1-OSC_OUT.Signal=RCC_OSC_OUT

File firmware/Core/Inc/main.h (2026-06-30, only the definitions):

#define LED_RED_Pin LL_GPIO_PIN_0
#define LED_RED_GPIO_Port GPIOA
#define LED_GREEN_Pin LL_GPIO_PIN_1
#define LED_GREEN_GPIO_Port GPIOA
#define LED_BLUE_Pin LL_GPIO_PIN_2
#define LED_BLUE_GPIO_Port GPIOA
#define BATT_VOLT_Pin LL_GPIO_PIN_3
#define BATT_VOLT_GPIO_Port GPIOA
#define IMU_CS_Pin LL_GPIO_PIN_4
#define IMU_CS_GPIO_Port GPIOA
#define IMU_SCL_Pin LL_GPIO_PIN_5
#define IMU_SCL_GPIO_Port GPIOA
#define IMU_MISO_Pin LL_GPIO_PIN_6
#define IMU_MISO_GPIO_Port GPIOA
#define IMU_MOSI_Pin LL_GPIO_PIN_7
#define IMU_MOSI_GPIO_Port GPIOA
#define IMU_INT1_Pin LL_GPIO_PIN_0
#define IMU_INT1_GPIO_Port GPIOB
#define IMU_INT1_EXTI_IRQn EXTI0_IRQn
#define CHG_INT_Pin LL_GPIO_PIN_1
#define CHG_INT_GPIO_Port GPIOB
#define IMU_INT2_Pin LL_GPIO_PIN_2
#define IMU_INT2_GPIO_Port GPIOB
#define IMU_INT2_EXTI_IRQn EXTI2_IRQn
#define ZERO_BUTTON_Pin LL_GPIO_PIN_10
#define ZERO_BUTTON_GPIO_Port GPIOB
#define HOLD_BUTTON_Pin LL_GPIO_PIN_11
#define HOLD_BUTTON_GPIO_Port GPIOB
#define ST7735S_CS_Pin LL_GPIO_PIN_12
#define ST7735S_CS_GPIO_Port GPIOB
#define ST7735S_SCL_Pin LL_GPIO_PIN_13
#define ST7735S_SCL_GPIO_Port GPIOB
#define ST7735S_MOSI_Pin LL_GPIO_PIN_15
#define ST7735S_MOSI_GPIO_Port GPIOB
#define BATT_EN_Pin LL_GPIO_PIN_8
#define BATT_EN_GPIO_Port GPIOA
#define FTDI_TX_Pin LL_GPIO_PIN_9
#define FTDI_TX_GPIO_Port GPIOA
#define FTDI_RX_Pin LL_GPIO_PIN_10
#define FTDI_RX_GPIO_Port GPIOA
#define ST7735S_DC_Pin LL_GPIO_PIN_11
#define ST7735S_DC_GPIO_Port GPIOA
#define ST7735S_RST_Pin LL_GPIO_PIN_12
#define ST7735S_RST_GPIO_Port GPIOA
#define DEBUG_SWDIO_Pin LL_GPIO_PIN_13
#define DEBUG_SWDIO_GPIO_Port GPIOA
#define DEBUG_SWCLK_Pin LL_GPIO_PIN_14
#define DEBUG_SWCLK_GPIO_Port GPIOA
#define ST7735S_BL_Pin LL_GPIO_PIN_15
#define ST7735S_BL_GPIO_Port GPIOA
#define DEBUG_OUT_Pin LL_GPIO_PIN_4
#define DEBUG_OUT_GPIO_Port GPIOB
#define CHG_SCL_Pin LL_GPIO_PIN_6
#define CHG_SCL_GPIO_Port GPIOB
#define CHG_SDA_Pin LL_GPIO_PIN_7
#define CHG_SDA_GPIO_Port GPIOB

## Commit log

2023-09-28 fix ADXL SPI configuration
    [STM32-leveler.ioc, main.c]
2023-09-28 attempt to use FIFO interrupts
2023-09-28 fix watermark interrupt issue
2023-09-30 enable I2C1 in normal mode for SSD1306
2023-09-30 move accelerometer to its own directory
2023-10-02 replace the SSD1306 protocol from I2C to SPI
    [STM32-leveler.ioc, main.c, main.h]
2023-10-02 add a CS pin for SPI2 + add comments
2023-10-02 add a DC pin
2023-10-02 add a reset pin
2023-10-02 start implementing the chip initialisation and SPI control
2023-10-03 implement a screen timer
2023-10-21 implement function to print angles on the screen
2023-10-21 fix issue with negative angles
    [main.c]
2023-10-24 remove driver-specific files
2023-10-25 make main update the ADXL module ID if error
    [main.c]
2023-10-31 make sampling interrupt more robust
2023-11-02 place angle printing in its own state
2023-11-02 change the screen transmission method to DMA
2023-11-02 move flag reset before DMA transmission
2023-11-02 implement a DMA timeout safeguard
2023-11-02 abort dma transmission if timeout
2023-11-11 move screen buffer formatting for angles to printAngle()
2023-11-11 make screen wiping use DMA
2025-11-13 refactor: design PCB rev0.2 (#21)
    [leany.kicad_pcb, leany.kicad_sch, power_management.kicad_sch]
2025-11-13 feat: Implement the ST7735S (#4)
    [1.8_inches_128x160_RGB_TFT_LCD_Pablo-Queiroz.stp, SW-DTSM-66N-V_Nicola-Stelian-Stefan.stp, Spacer M2 M F 10mm_mart-berghs.stp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]
2025-11-13 refactor: move code to firmware/ and schematics to pcb/ (#25)
    [1.8_inches_128x160_RGB_TFT_LCD_Pablo-Queiroz.stp, 2020-RGB-LED.step, SW-DTSM-66N-V_Nicola-Stelian-Stefan.stp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]
2025-11-13 refactor: replace the LSM6DSO by a BMI270 (#5)
    [leany.kicad_pcb, leany.kicad_sch]
2025-11-13 perf: strenghen Mahony filter (#50)
    [leany.kicad_pcb, leany.kicad_sch, power_management.kicad_sch]
2025-11-13 feat: Use and enfore REUSE copyright tool (#35)
    [1.8_inches_128x160_RGB_TFT_LCD_Pablo-Queiroz.stp, 2020-RGB-LED.step, SW-DTSM-66N-V_Nicola-Stelian-Stefan.stp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]
2025-11-13 feat: Implement GPIO task with LED state machine (#13)
2025-11-13 feat: implement generic IMU task and API (#63)
2025-11-13 feat: design PCB rev0.3 (#27)
    [SOP-8.step, leany.kicad_pcb, leany.kicad_sch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]
2025-11-13 feat: Implement serial commands and logging (#18)
    [leany.kicad_pcb, leany.kicad_sch, power_management.kicad_sch]
2025-12-26 chore: unify config files and scripts + fix linter issues (#76)
    [lsm6.c]
2026-03-09 refactor: design PCB rev0.4 and fix validation workflow (#64)
    [1.8_inches_128x160_RGB_TFT_LCD_Pablo-Queiroz.stp, 2020-RGB-LED.step, SOP-8.step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]
2026-03-14 feat: Implement the battery task and BQ25619 library (#12)
2026-03-14 style: get rid of Ticktype_t in hal-i2c.c (#12)
2026-03-14 fix: remove the second charger status reading (#12)
    [bq25619.c]
2026-03-14 refactor: make battery status reentrant (#12)
2026-03-14 feat: implement charger hardware event (#12)
2026-03-14 feat: implement battery level reading (#12)
2026-03-14 perf: replace the adc binary semaphore by a simple flag (#12)
    [hal_adc.c, task_gpio.c]
2026-03-14 refactor: make adc generic and separate temperature from adc (#12)
2026-03-14 refactor: enable second ADC rank and DMA (#12)
2026-03-14 feat: implement battery voltage measurement (#12)
2026-03-14 perf: add a delay after charger reset (#12)
    [task_battery.c]
2026-03-14 refactor: Change battery voltage representation to hundredths (#12)
2026-03-14 refactor: improve ADC reference values (#12)
2026-03-14 style: move temperature calculation to gpio task (#12)
2026-03-14 refactor: move temperature GPIO management to GPIO task (#12)
2026-03-14 style: split up battery request and update (#12)
2026-03-14 feat: start measuring VrefInt to make ADC measurements more precise (#12)
2026-03-14 refactor: simplify ADC readings (#12)
2026-03-14 perf: use battery power path switching (#12)
2026-03-14 feat: implement battery voltage averaging (#12)
2026-03-14 style: move battery voltage update to battery task (#12)
2026-03-14 feat: implement the battery level lookup table (#12)
2026-03-14 feat: add battery voltage to system screen (#12)
2026-03-14 feat: implement low battery system shutdown (#12)
2026-05-06 refactor: reuse isContextReset() in bad samples count test (#53)
2026-05-06 fix: start fixing new compile errors (#53)
    [lsm6.c]
2026-06-30 refactor: fallback to rev 0.3 and update files (#98)
    [1.8_inches_128x160_RGB_TFT_LCD_Pablo-Queiroz.stp, 2020-RGB-LED.step, SOP-8.step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]
2026-06-30 fix: remove test points from BOM and CPL (#98)
    [leany.kicad_pcb, leany.kicad_sch, power_management.kicad_sch]
2026-06-30 fix: re-configure project so it fits rev 0.3 (#98)
    [Leany.ioc, main.c, main.h]
2026-07-02 refactor: move sensor fusion module to app/ (#78)
2026-07-02 refactor: remove imu-specific clang-tidy configuration (#78)
2026-07-02 ci: fix linters errors (#78)
    [hal_adc.c, hal_spi.c, scpi_commands.c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]
2026-07-02 ci: make lizard ignore serial tasks switches (#78)
2026-07-05 fix: improve tasks stack overflow management (#100)
    [Leany.ioc, task_battery.c, task_gpio.c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]
2026-09-08 refactor: get rid of all trace of float management (#103)
    (cherry picked from commit 8f504375c9216869deff7992697b5320ffda1f3c)
2026-09-08 feat: implement characters printing (#103)
    (cherry picked from commit 57485d5d52c134a8136e55fe88e640507aa85ad6)
2026-09-08 refactor: fix float 0 precision and padding printing (#103)
    (cherry picked from commit 7e5009dc8a3e1b6470da0123676fe1456ba0346e)
2026-09-17 refactor: improve IMU task weaknesses (#48)
2026-09-17 feat: raise IMU task priority (#48)
2026-09-17 refactor: improve IMU self-testing (#48)
2026-09-17 style: rename imu ticks variables (#48)
2026-09-17 style: rename sensorfusion to mahony (#48)
2026-09-17 feat: make mahony filter return update status (#48)
2026-09-17 refactor: reduce IMU ODR and AXL cutoff frequency (#48)
2026-09-17 refactor: replace leany_std by custom_string (#48)
    [lsm6.c, task_serial.c]
2026-09-17 feat: track FreeCAD files into Git LFS (#45)
2026-09-17 feat: start designing the test angled bracket and slide-in support (#45)
    [angled_bracket.FCStd, support_plate.FCStd]
2026-09-17 feat: start reimplementing mount plate (#45)
    [mount_plate.FCStd, pcb_coordinates.FCStd]
2026-09-17 feat: replace stl files creation by step files (#45)
2026-09-17 feat: add features to the mounting plate (#45)
    [mount_plate.FCStd]
2026-09-17 feature: adapt jig design to the new pcb (#45)
    [angled_bracket.FCStd, mount_plate.FCStd, pcb_coordinates.FCStd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]
2026-09-17 style: move validation script file and rename CAD/ to cad/ (#45)
    [angled_bracket.FCStd, pcb_coordinates.FCStd, support_plate.FCStd]
2026-09-17 refactor : fix kicad_pcb files rules in gitattributes (#45)

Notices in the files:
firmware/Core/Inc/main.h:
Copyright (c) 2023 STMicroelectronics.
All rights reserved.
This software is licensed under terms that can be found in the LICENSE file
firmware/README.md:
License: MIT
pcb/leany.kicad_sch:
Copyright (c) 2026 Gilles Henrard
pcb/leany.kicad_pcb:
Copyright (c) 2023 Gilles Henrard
